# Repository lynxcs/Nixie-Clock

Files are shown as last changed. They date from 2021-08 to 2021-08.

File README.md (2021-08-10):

<p align="center">

  <h1 align="center"><b>Nixie Clock</b></h1>

  <p align="center">
    Nixie clock for my design class, including the 3D renders, PCB design and photos of the finished pcb.
  </p>

<p align="center">
  <a align="center" href="https://github.com/lynxcs/nixie-clock">
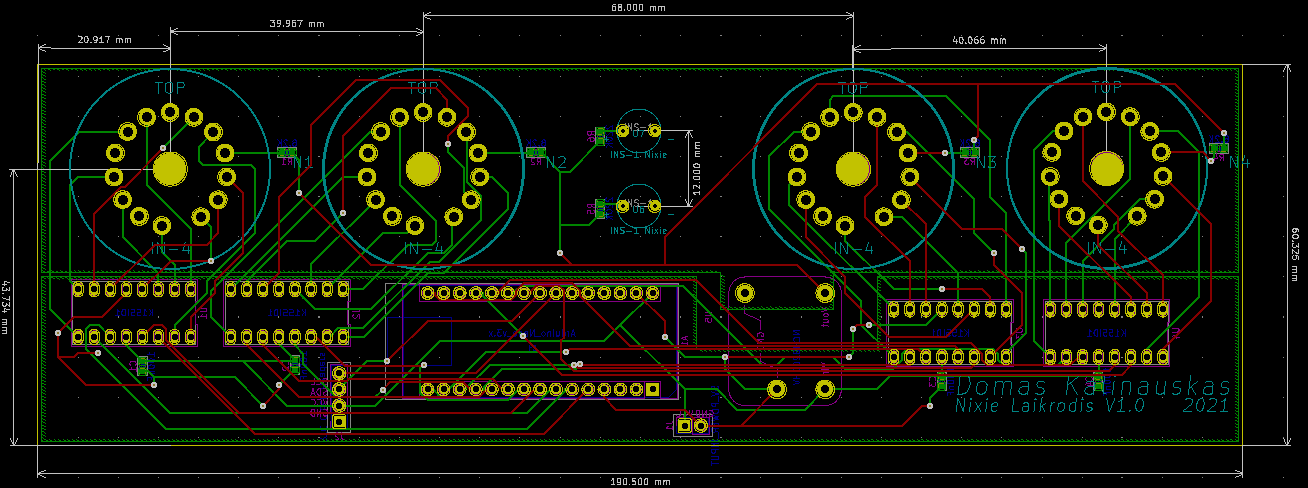
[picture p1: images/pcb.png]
PCB
    
  </a>
  </p>
</p>

<!-- ABOUT THE PROJECT -->
# About The Project
<a href="https://github.com/lynxcs/Nixie-Clock/blob/master/aprasymas.pdf">Details in lithuanian here</a>

## Tools used
<p>
    The nixie clock was made using Blender, inkscape and kicad.
</p>

## 3D Model
<p>First the 3D render was created as a rough idea about how I wanted the clock to look</p>
  <a href="https://github.com/lynxcs/nixie-clock">
    Render
  </a>

## Case design
<p> Afterward I designed a blueprint with the dimensions for the case design </p>
  <a href="https://github.com/lynxcs/nixie-clock">
    Case
  </a>

## Schematic
<p> Upon completion of the case design, I started to work on the schematic </p>
  <a href="https://github.com/lynxcs/nixie-clock">
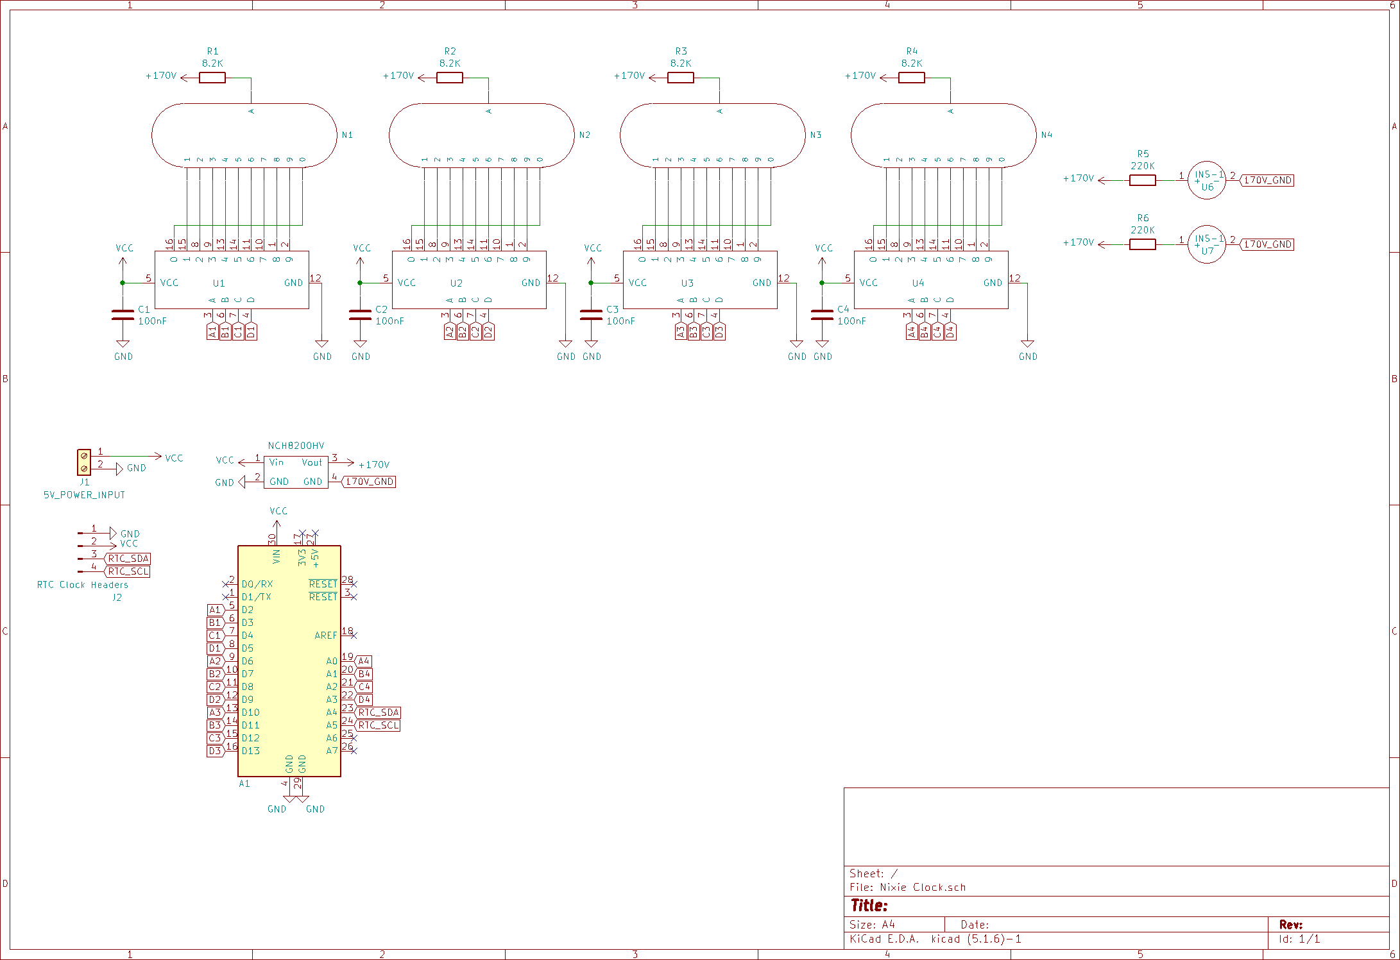
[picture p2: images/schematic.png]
Schematic
    
  </a>

## Components
<p>
    The PCB makes use of several components. The key components have been listed below
    <ul>
    <li>Arduino Pro Mini</li>
    <li>IN-4 Nixie Digits</li>
    <li>INS-1 Nixie Indicators</li>
    <li>K155ID1 high voltage drivers</li>
    <li>NCH8200HV high voltage boost converter (5v to 170v)</li>
    </ul>
</p>

## PCB Layout
<p> Then I made the PCB layout, trying my best to make it as small as possible, though sadly it wouldn't fit in the original case design dimensions</p>
  <a href="https://github.com/lynxcs/nixie-clock">
    Schematic
  </a>

## Assembly
<p> Lastly I ordered the PCB's and got to soldering and programming</p>
  <a href="https://github.com/lynxcs/nixie-clock">
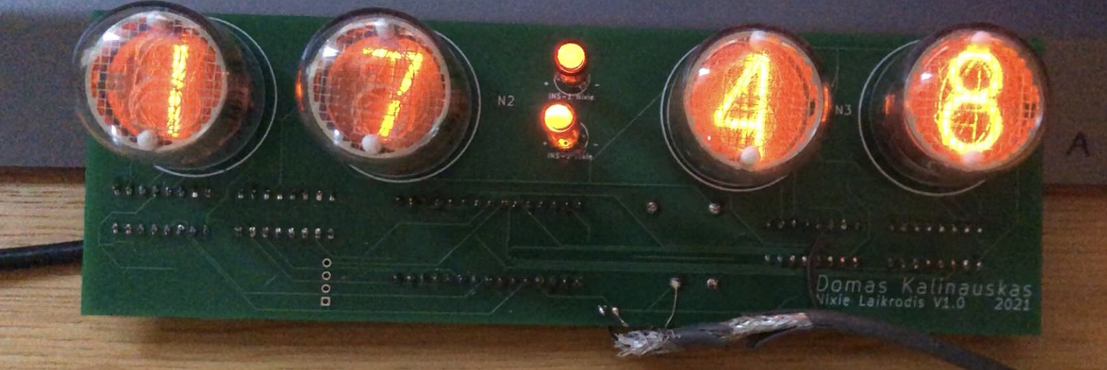
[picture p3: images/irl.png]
    
  </a>

## Case mounting
<p><i>This part is still W.I.P</i></p>

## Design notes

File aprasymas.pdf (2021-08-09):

# “Nixie tube” laikrodis

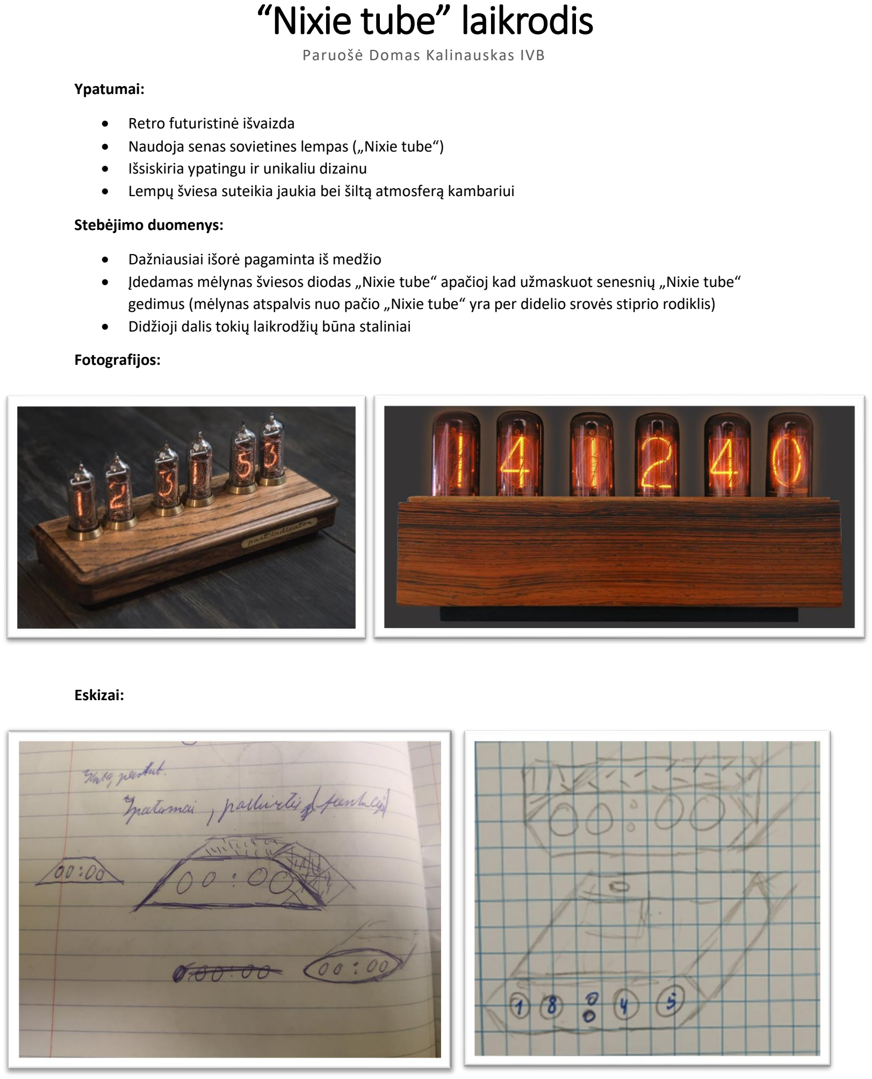
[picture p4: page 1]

Paruošė Domas Kalinauskas IVB

Ypatumai:

- Retro futuristinė išvaizda
- Naudoja senas sovietines lempas („Nixie tube“)
- Išsiskiria ypatingu ir unikaliu dizainu
- Lempų šviesa suteikia jaukia bei šiltą atmosferą kambariui

Stebėjimo duomenys:

- Dažniausiai išorė pagaminta iš medžio
- Įdedamas mėlynas šviesos diodas „Nixie tube“ apačioj kad užmaskuot senesnių „Nixie tube“ gedimus (mėlynas atspalvis nuo pačio „Nixie tube“ yra per didelio srovės stiprio rodiklis)
- Didžioji dalis tokių laikrodžių būna staliniai

Fotografijos:

Eskizai:

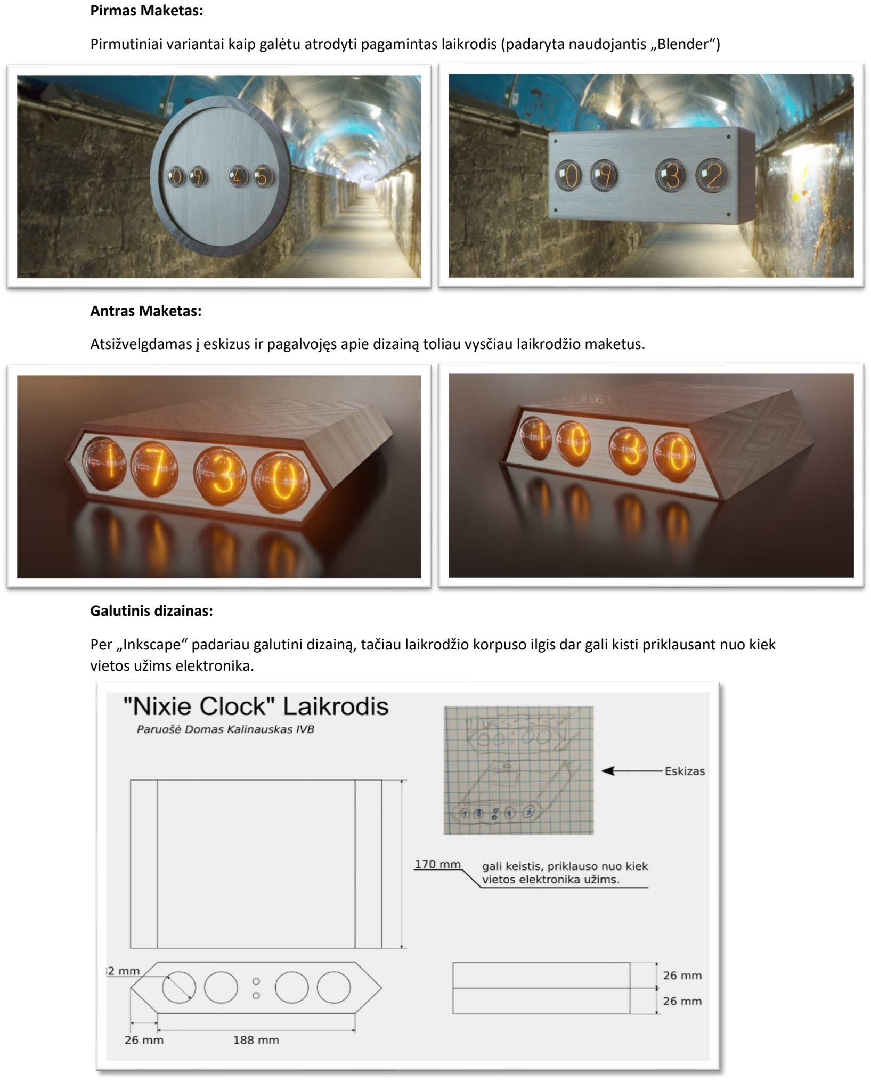
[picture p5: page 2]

Pirmas Maketas:

Pirmutiniai variantai kaip galėtu atrodyti pagamintas laikrodis (padaryta naudojantis „Blender“)

Antras Maketas:

Atsižvelgdamas į eskizus ir pagalvojęs apie dizainą toliau vysčiau laikrodžio maketus.

Galutinis dizainas:

Per „Inkscape“ padariau galutini dizainą, tačiau laikrodžio korpuso ilgis dar gali kisti priklausant nuo kiek vietos užims elektronika.

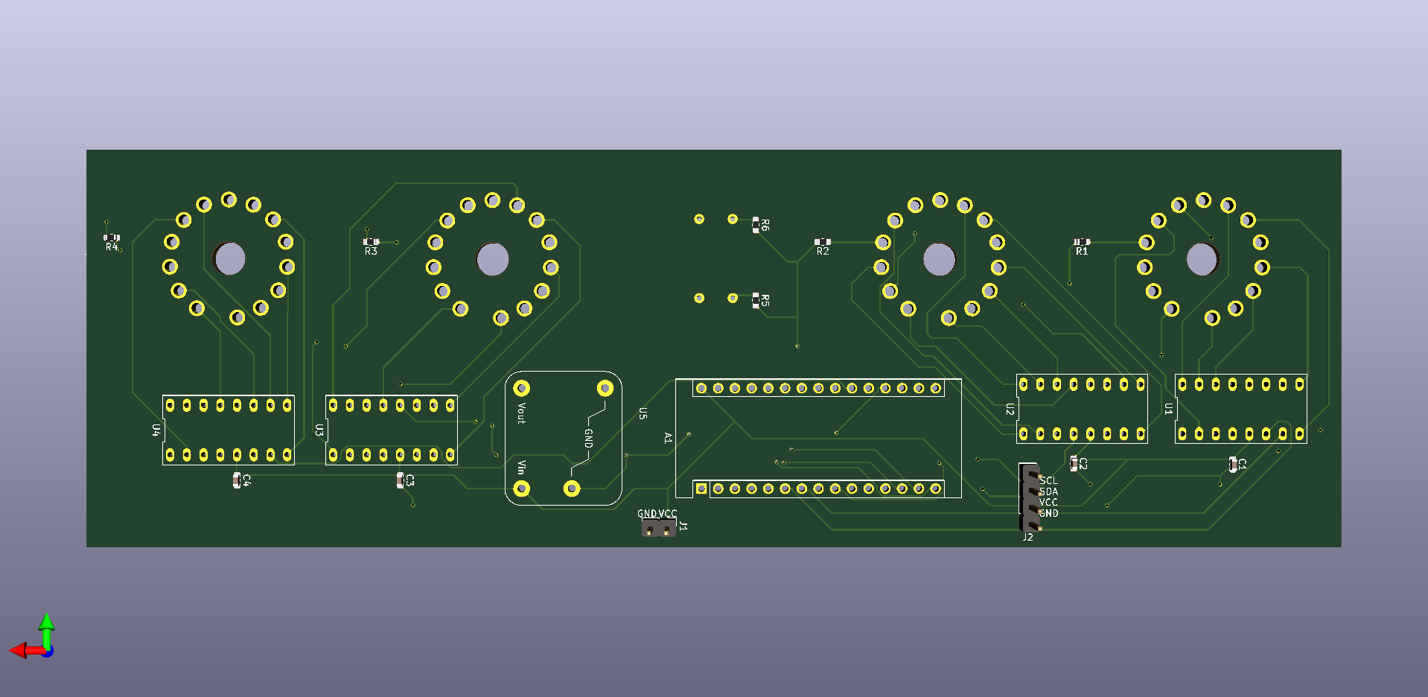
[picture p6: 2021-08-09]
images/back.png

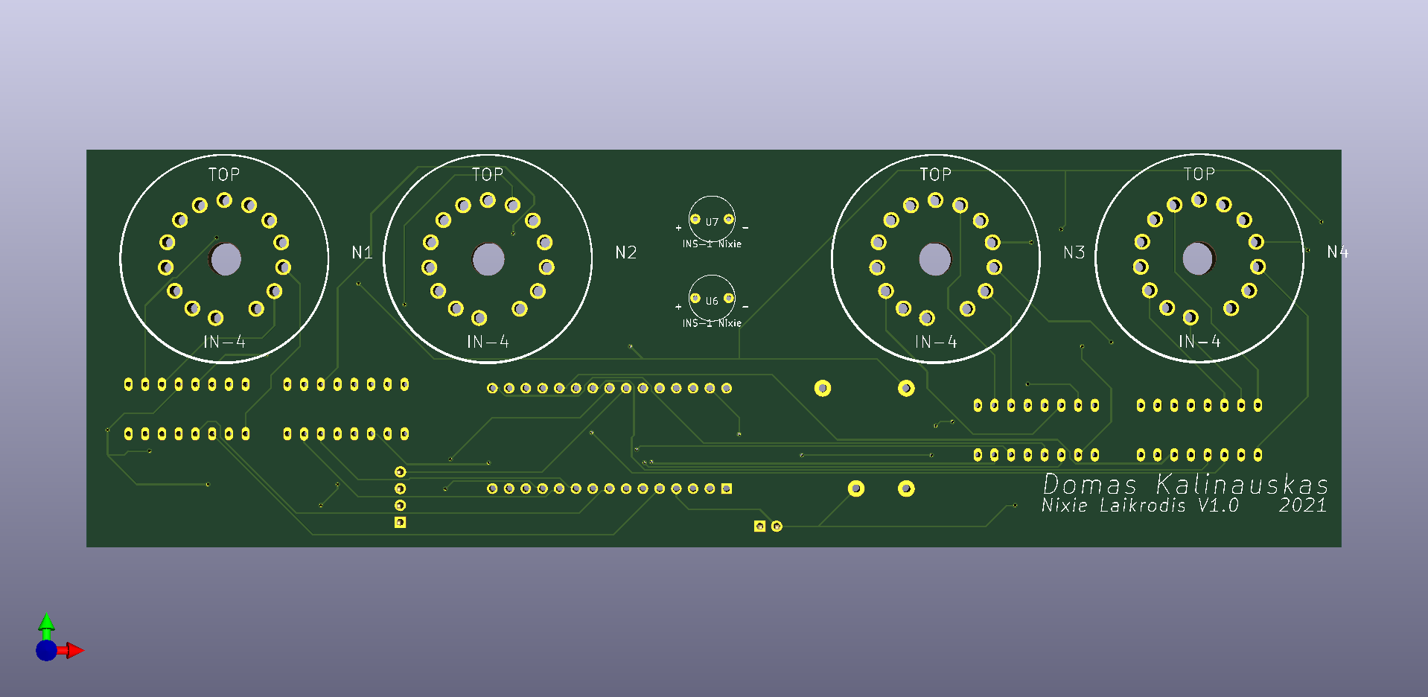
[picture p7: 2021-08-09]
images/front.png

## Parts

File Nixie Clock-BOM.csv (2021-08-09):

Comment | Designator | Footprint | LCSC Part Number
100nF | C1,C2,C3,C4 | 0603 | C14663
8K2 | R1,R2,R3,R4 | 0603 | C25981
220K | R5,R6 | 0603 | C22961

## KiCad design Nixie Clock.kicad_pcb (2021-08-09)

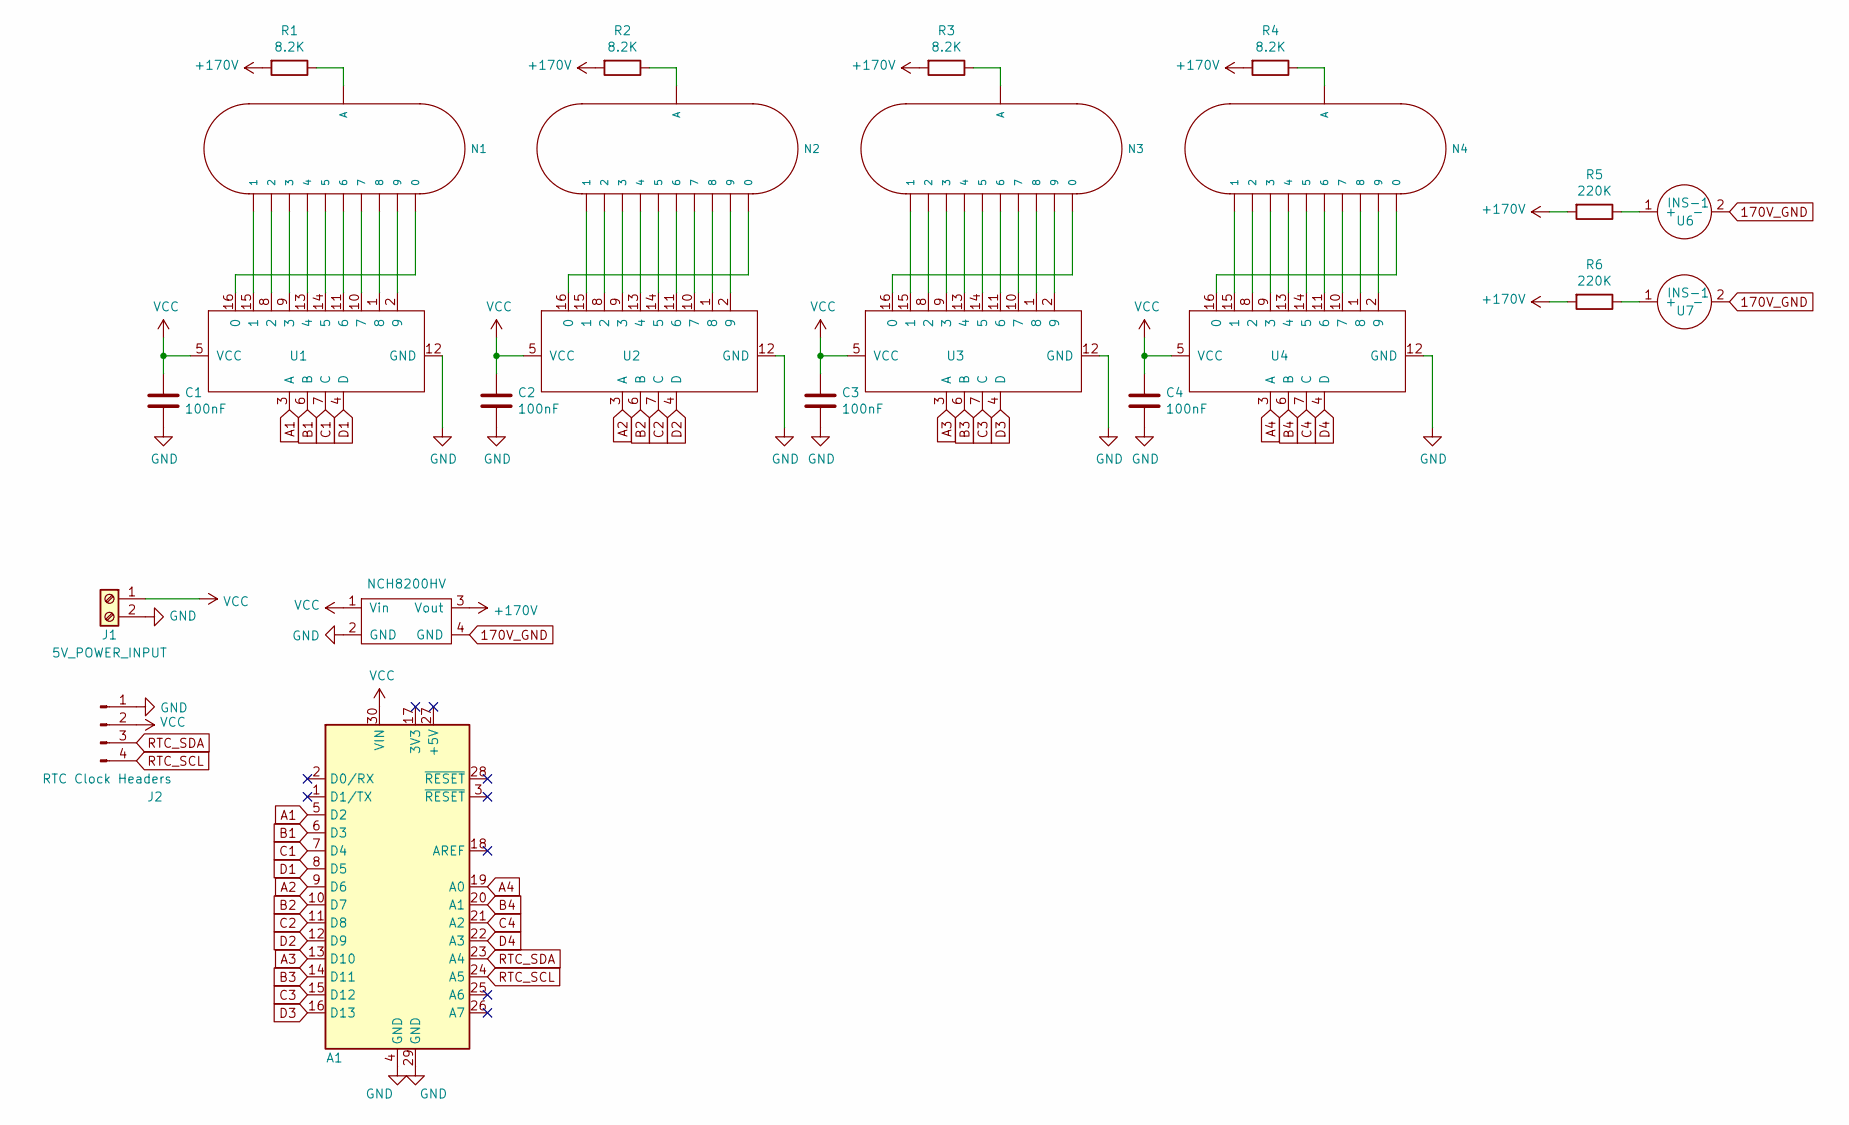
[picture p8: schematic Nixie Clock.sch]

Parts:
A1: Arduino_Nano_v3.x; Arduino_Nano
C1, C2, C3, C4: 100nF; C_0603_1608Metric; LCSC C15725
J1: 5V_POWER_INPUT; PinHeader_1x02_P2.54mm_Vertical
J2: RTC Clock Headers; PinHeader_1x04_P2.54mm_Vertical
N1, N2, N3, N4: IN-4; nixies-us-IN-4-DSUB
R1, R2, R3, R4: 8.2K; R_0603_1608Metric; LCSC C25981
R5, R6: 220K; R_0603_1608Metric; LCSC C22961
U1, U2, U3, U4: K155ID1
U5: NCH8200HV
U6, U7: INS-1

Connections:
170V_GND: U5.4 (GND), U6.2 (-), U7.2 (-)
+170V: R1.2, R2.2, R3.2, R4.2, R5.2, R6.2, U5.3 (Vout)
A1: A1.5 (D2), U1.3 (A)
A2: A1.9 (D6), U2.3 (A)
A3: A1.13 (D10), U3.3 (A)
A4: A1.19 (A0), U4.3 (A)
B1: A1.6 (D3), U1.6 (B)
B2: A1.10 (D7), U2.6 (B)
B3: A1.14 (D11), U3.6 (B)
B4: A1.20 (A1), U4.6 (B)
C1: A1.7 (D4), U1.7 (C)
C2: A1.11 (D8), U2.7 (C)
C3: A1.15 (D12), U3.7 (C)
C4: A1.21 (A2), U4.7 (C)
D1: A1.8 (D5), U1.4 (D)
D2: A1.12 (D9), U2.4 (D)
D3: A1.16 (D13), U3.4 (D)
D4: A1.22 (A3), U4.4 (D)
GND: A1.4 (GND), A1.29 (GND), C1.2, C2.2, C3.2, C4.2, J1.2, J2.1, U1.12 (GND), U2.12 (GND), U3.12 (GND), U4.12 (GND), U5.2 (GND)
unnamed: N1.0, U1.16 (0)
unnamed: N1.1, U1.15 (1)
unnamed: N1.2, U1.8 (2)
unnamed: N1.3, U1.9 (3)
unnamed: N1.4, U1.13 (4)
unnamed: N1.5, U1.14 (5)
unnamed: N1.6, U1.11 (6)
unnamed: N1.7, U1.10 (7)
unnamed: N1.8, U1.1 (8)
unnamed: N1.9, U1.2 (9)
unnamed: N1.A3 (A), R1.1
unnamed: N2.0, U2.16 (0)
unnamed: N2.1, U2.15 (1)
unnamed: N2.2, U2.8 (2)
unnamed: N2.3, U2.9 (3)
unnamed: N2.4, U2.13 (4)
unnamed: N2.5, U2.14 (5)
unnamed: N2.6, U2.11 (6)
unnamed: N2.7, U2.10 (7)
unnamed: N2.8, U2.1 (8)
unnamed: N2.9, U2.2 (9)
unnamed: N2.A3 (A), R2.1
unnamed: N3.0, U3.16 (0)
unnamed: N3.1, U3.15 (1)
unnamed: N3.2, U3.8 (2)
unnamed: N3.3, U3.9 (3)
unnamed: N3.4, U3.13 (4)
unnamed: N3.5, U3.14 (5)
unnamed: N3.6, U3.11 (6)
unnamed: N3.7, U3.10 (7)
unnamed: N3.8, U3.1 (8)
unnamed: N3.9, U3.2 (9)
unnamed: N3.A3 (A), R3.1
unnamed: N4.0, U4.16 (0)
unnamed: N4.1, U4.15 (1)
unnamed: N4.2, U4.8 (2)
unnamed: N4.3, U4.9 (3)
unnamed: N4.4, U4.13 (4)
unnamed: N4.5, U4.14 (5)
unnamed: N4.6, U4.11 (6)
unnamed: N4.7, U4.10 (7)
unnamed: N4.8, U4.1 (8)
unnamed: N4.9, U4.2 (9)
unnamed: N4.A3 (A), R4.1
unnamed: R5.1, U6.1 (+)
unnamed: R6.1, U7.1 (+)
RTC_SCL: A1.24 (A5), J2.4
RTC_SDA: A1.23 (A4), J2.3
VCC: A1.30 (VIN), C1.1, C2.1, C3.1, C4.1, J1.1, J2.2, U1.5 (VCC), U2.5 (VCC), U3.5 (VCC), U4.5 (VCC), U5.1 (Vin)

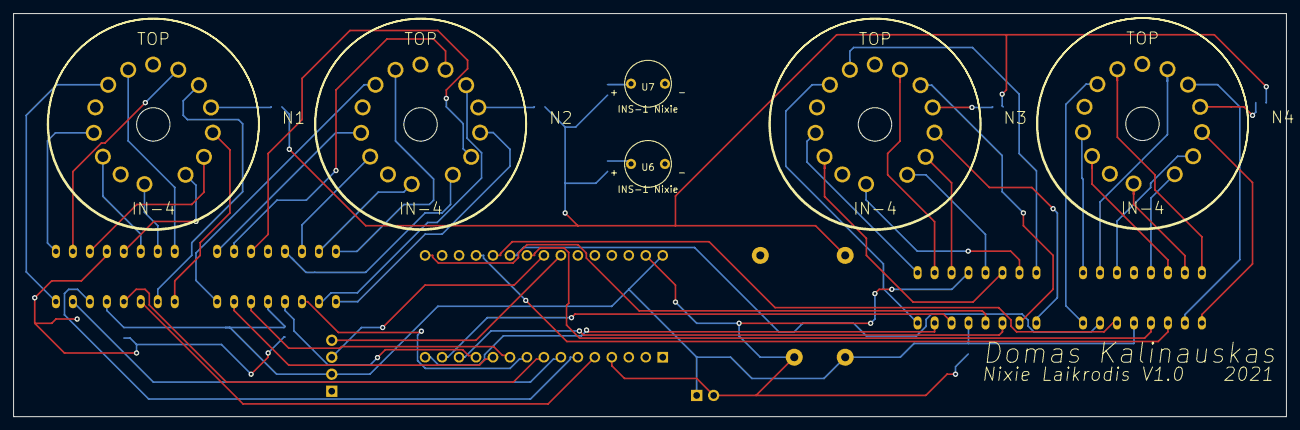
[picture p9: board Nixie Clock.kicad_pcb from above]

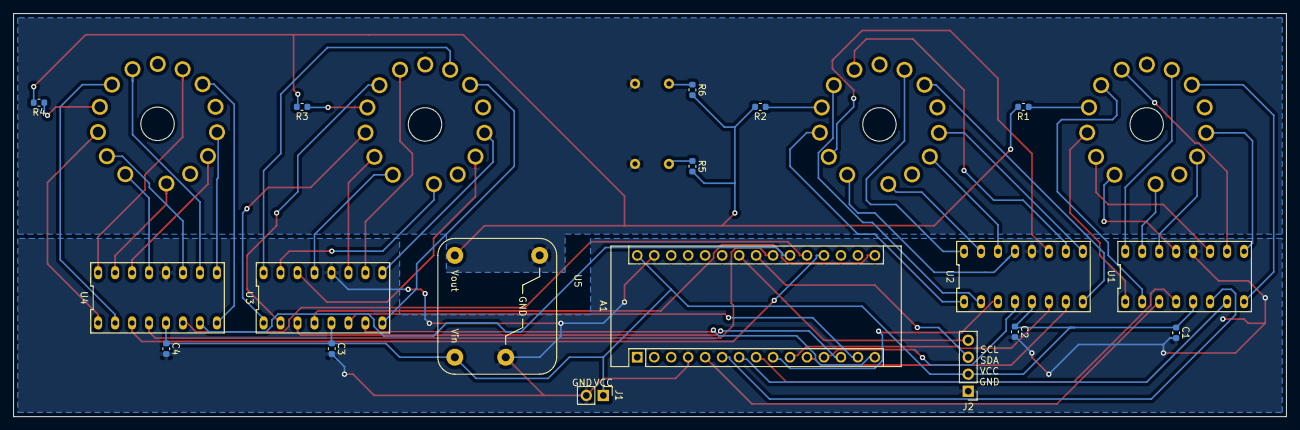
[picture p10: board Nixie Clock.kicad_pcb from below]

Board: 2 copper layers, 190.5 x 60.3 mm, 24 parts (18 on the bottom side), 68 nets.

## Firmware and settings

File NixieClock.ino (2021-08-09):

#define QA1 2
#define QB1 3
#define QC1 4
#define QD1 5
#define QA2 6
#define QB2 7
#define QC2 8
#define QD2 9
#define QA3 10
#define QB3 11
#define QC3 12
#define QD3 13
#define QA4 A0
#define QB4 A1
#define QC4 A2
#define QD4 A3

#include <Wire.h>
#include "RTClib.h"
#include <String.h>
RTC_DS1307 rtc;

unsigned int digits[4][4] = {{QA1,QB1,QC1,QD1}, {QA2,QB2,QC2,QD2}, {QA3,QB3,QC3,QD3}, {QA4,QB4,QC4,QD4}};

int current_hour;
int current_minute;
int current_second;

void setup() {
  Serial.begin(9600);
  Serial.println(__TIME__);

  if (! rtc.begin())
  {
    Serial.println("Couldn't find RTC");
    while (1);
  }
  if (! rtc.isrunning())
  {
    Serial.println("RTC is NOT running!");
    //rtc.adjust(DateTime(F(__DATE__), F(__TIME__)));
  }



  for(int i = 0; i < 4; i++)
  {
  pinMode(digits[i][0], OUTPUT);
  pinMode(digits[i][1], OUTPUT);
  pinMode(digits[i][2], OUTPUT);
  pinMode(digits[i][3], OUTPUT);
  }

  current_hour = 0;
  current_minute = 0;
}

void loop() {
  if (Serial.available() > 0) {
    String time = Serial.readString();
    Serial.println("Read string");
    rtc.adjust(DateTime(time.toInt()));
  }


  DateTime now = rtc.now();
  current_hour = now.hour();
  current_minute = now.minute();
  writenumber(current_hour/10, 0);
  writenumber(current_hour % 10, 1);
  writenumber(current_minute/10, 2);
  writenumber(current_minute%10, 3);
  Serial.print("Current time: ");
  Serial.print(current_hour);
  Serial.print(":");
  Serial.println(current_minute);
  delay(100);
}

void writenumber(unsigned int number, unsigned int digit)
{
  digitalWrite(digits[digit][0], number & (1 << 0));
  digitalWrite(digits[digit][1], number & (1 << 1));
  digitalWrite(digits[digit][2], number & (1 << 2));
  digitalWrite(digits[digit][3], number & (1 << 3));  
}

void scrolldown(unsigned int number, unsigned int digit)
{
  if (digit == 3)
  {
    Serial.println("Counting down last digit...");
    while(number != -1)
    {
      writenumber(number, digit);
      number--;
      delay(20);
    }
  }
  if (digit == 2)
  {
    Serial.println("Counting down third digit...");
    while(number != 0)
    {
      scrolldown(9, 3);
      number--;
      writenumber(number, digit);
      writenumber(9, 3);
      //delay(20);
    }
    scrolldown(9, 3);
  }
  if (digit == 1)
  {
    while(number != 0)
    {
      scrolldown(6, 2);
      number--;
      writenumber(number, digit);
      //delay(20);
    }
  }
  if (digit == 0)
  {
    while(number != 0)
    {
      scrolldown(4, 1);
      number--;
      writenumber(number, digit);
      //delay(20);
    }
  }
}
